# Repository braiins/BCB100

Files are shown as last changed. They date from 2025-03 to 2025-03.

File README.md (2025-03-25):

**Product Description**

This is final production release of Braiins BCB100.

**Hardware features**

- Compatible with all s19 models with the exception of Hydro models.
- Easy installation - compatible with the standard enclosures.
- SD Card slot
- LEDs
- Ethernet port
- Immersion ready
- It is based on MPU STM32MP157C/F with part number STM32MP157CAB3. Two core 650MHz A7 with ARM ISA and Cortex M3
  coprocessor. Package is LFBGA354 16x16
- 128 MB RAM and 4GB of eMMC memory
- Ethernet connection is based on Ethernet PHY Microchip 8710 with 10/100 Mb connection
- Main power is 12V with discrete points of 3.3V/1.35 and 0.65V, for the MPU, RAM, eMMC, Ethernet PHY and rest of the
  active components

**Software features**

- Full support of Braiins OS+

**Dimensions**

- Height: 110mm
- Width:100mm
- Weight:  ~130g

By default the board is powered by 12V from the auxiliary part of the PSU with a standard connector.
On the control board there are multiple discrete voltage points for the MPU, RAM, eMMC and Ethernet PHY. Discrete
voltage map contains 12V as the main power supply, 3.3V(eMMC, Ethernet PHY, OP-AMP) for multiple active components,
1.35V for the MPU/RAM and 0.65V for RAM as a reference voltage. MPU on the control board is from ST company with 2 ISA
ARM A7 cores 650 MHZ with M3 co-processor for smooth run.
Package is LFBGA354 16X16 part number STM32MP157CAB3. Operating memory is provided by Micron with a density 128MB. The
control board has two parts which can provide storage and boot capability.
First one is eMMC memory from company Alliance Memory with density 4GB. By default eMMC is chosen as the default boot
option. Second possibility for storage and OS boot is an SD card.
When the SD card is inserted during successful OS boot from eMMC, the MPU must be reset by reset button and after reset
the MPU will boot OS from the SD card.
Ethernet connection is secured by Ethernet PHY from company Microchip. It has a standard 10/100 Mb connection speed.
Board is built on the 6 layer PCB with 4 layers for data connections and 2 layers for power and ground to ensure proper
board running without cross talking or any other types of noise.
The control board mask was chosen black with a silicon layer for marks and signs. Parts on control boards are from both
sides of the board(top and bottom layer).
Current consumption on average is 250 mA.

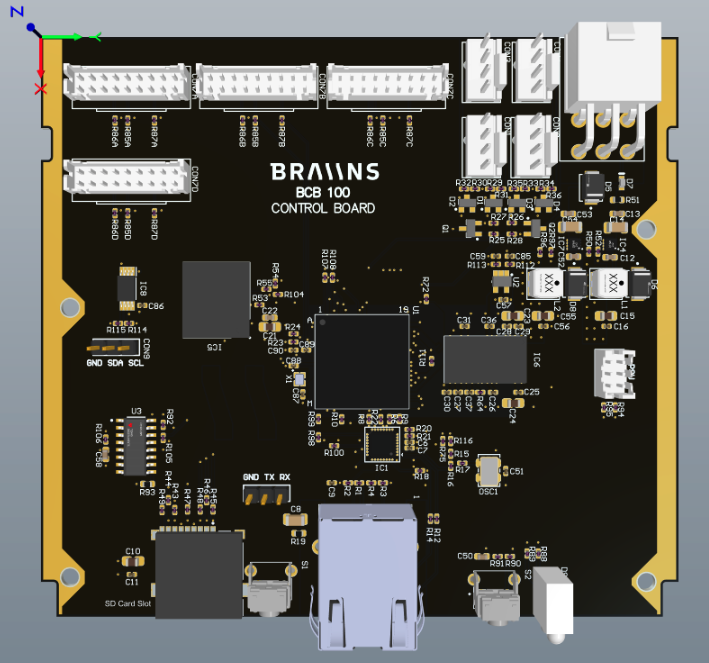
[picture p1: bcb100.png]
Braiins Control Board - BCB100


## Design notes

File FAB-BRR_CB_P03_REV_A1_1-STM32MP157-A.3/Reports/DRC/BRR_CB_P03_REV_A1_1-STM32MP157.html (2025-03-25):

Altium

# Design Rule Verification Report

Date: | | 25. 3. 2025
Time: | | 9:34:08
Elapsed Time: | | 00:00:02
Filename: | | C:\Users\Richard Tomasovic\AppData\Local\Temp\Releases\Snapshot\1\BRR_CB_P03_REV_A1_1-STM32MP157.PcbDoc

Warnings: | | 0
Rule Violations: | | 0
Waived Violations: | | 16

## Summary

Warnings | Count
Total | 0

Rule Violations | Count
Clearance Constraint (Gap=0.151mm) (All),(All) | 0
Clearance Constraint (Gap=0.102mm) (WithinRoom('MPU_BGA')),(All) | 0
Clearance Constraint (Gap=0.102mm) (WithinRoom('RAM')),(All) | 0
Clearance Constraint (Gap=0.102mm) (WithinRoom('EMMC')),(All) | 0
Clearance Constraint (Gap=0.102mm) (InNetClass('SINGLE_55R_DDR')),(All) | 0
Clearance Constraint (Gap=0.506mm) (InNet('NetC1_1') and InPolygon),(All) | 0
Clearance Constraint (Gap=0.506mm) (OnLayer('Int1 (GND)')),(All) | 0
Clearance Constraint (Gap=0.5mm) (HasFootprint('FID_1MM')),(All) | 0
Clearance Constraint (Gap=0.102mm) ((InDifferentialPairClass('All Differential Pairs'))),(All) | 0
Clearance Constraint (Gap=0.254mm) (InPolygon),(All) | 0
Short-Circuit Constraint (Allowed=No) (All),(All) | 0
Un-Routed Net Constraint ( (All) ) | 0
Modified Polygon (Allow modified: No), (Allow shelved: No) | 0
Width Constraint (Min=0.044mm) (Max=0.145mm) (Preferred=0.089mm) (InNetClass('50R_SDMMC1')) | 0
Width Constraint (Min=0.031mm) (Max=0.12mm) (Preferred=0.077mm) (InNetClass('SINGLE_55R_DDR')) | 0
Width Constraint (Min=0.102mm) (Max=0.305mm) (Preferred=0.203mm) (All) | 0
Width Constraint (Min=0.17mm) (Max=0.5mm) (Preferred=0.254mm) (InNet('DDR_VREF')) | 0
Width Constraint (Min=0.102mm) (Max=0.305mm) (Preferred=0.16mm) (WithinRoom('RAM')) | 0
Width Constraint (Min=0.044mm) (Max=0.145mm) (Preferred=0.089mm) (InNetClass('50R_SDMMC2')) | 0
Power Plane Connect Rule(Relief Connect )(Expansion=0.508mm) (Conductor Width=0.254mm) (Air Gap=0.254mm) (Entries=4) (All) | 0
Hole Size Constraint (Min=0.2mm) (Max=6mm) (All) | 0
Hole To Hole Clearance (Gap=0.254mm) (All),(All) | 0
Minimum Solder Mask Sliver (Gap=0mm) (All),(All) | 0
Silk To Solder Mask (Clearance=0mm) (IsPad),(All) | 0
Silk to Silk (Clearance=0mm) (All),(All) | 0
Net Antennae (Tolerance=0mm) (All) | 0
Board Clearance Constraint (Gap=0mm) (All) | 0
Length Constraint (Min=0mm) (Max=100mm) (InNetClass('50R_SDMMC1')) | 0
Matched Lengths(Tolerance=2mm) (InNetClass('50R_SDMMC1')) | 0
Matched Lengths(Delay Tolerance=5ps) (InDifferentialPairClass('DIFF_100R_DDR')) | 0
Matched Lengths(Delay Tolerance=10ps) (InDifferentialPairClass('ETH_100R')) | 0
Matched Lengths(Tolerance=3mm) (InxSignalClass('DDR3')) | 0
Matched Lengths(Tolerance=1mm) (InxSignalClass('SDMMC2')) | 0
Matched Lengths(Delay Tolerance=10ps) (InDifferentialPairClass('DIFF_100R_DDR')) | 0
Matched Lengths(Delay Tolerance=5ps) (InDifferentialPairClass('ETH_100R')) | 0
Maximum Via Count Constraint (Limit=2) (InNetClass('SINGLE_55R_DDR')) | 0
Room U_HBInterface_1 (Bounding Region = (8.255mm, 28.068mm, 24.255mm, 50.068mm) (InComponentClass('U_HBInterface_1')) | 0
Room EMMC (Bounding Region = (43.855mm, 20.668mm, 62.655mm, 42.664mm) (InComponentClass('Room Definition1')) | 0
Room U_HBInterface_0 (Bounding Region = (8.255mm, 6.068mm, 24.255mm, 28.068mm) (InComponentClass('U_HBInterface_0')) | 0
Room U_HBInterface_2 (Bounding Region = (8.255mm, 50.068mm, 24.255mm, 72.068mm) (InComponentClass('U_HBInterface_2')) | 0
Room RAM (Bounding Region = (57.355mm, 68.668mm, 71.255mm, 86.168mm) (False) | 0
Room MPU_BGA (Bounding Region = (54.455mm, 46.968mm, 73.855mm, 65.168mm) (False) | 0
Room U_HBInterface_3 (Bounding Region = (24.255mm, 6.068mm, 40.255mm, 28.068mm) (InComponentClass('U_HBInterface_3')) | 0
Height Constraint (Min=0mm) (Max=25.4mm) (Prefered=12.7mm) (All) | 0
Total | 0

Waived Violations | Count
Board Clearance Constraint (Gap=0mm) (All) | 15
Maximum Via Count Constraint (Limit=2) (InNetClass('SINGLE_55R_DDR')) | 1
Total | 16

## Rule Violations

## Waived Violations

Board Clearance Constraint (Gap=0mm) (All)

Board Outline Clearance(Outline Edge): (Collision < 0.381mm) Between Board Edge And Track (0.1mm,104.1mm)(21.4mm,104.1mm) on Top Overlay
Waived by Richard Tomašoviè at 14. 5. 2023 16:14:11

Board Outline Clearance(Outline Edge): (Collision < 0.381mm) Between Board Edge And Track (0.1mm,89.5mm)(0.1mm,104.1mm) on Top Overlay
Waived by Richard Tomašoviè at 14. 5. 2023 16:14:14

Board Outline Clearance(Outline Edge): (Collision < 0.381mm) Between Board Edge And Track (0.1mm,89.5mm)(21.4mm,89.5mm) on Top Overlay
Waived by Richard Tomašoviè at 14. 5. 2023 16:14:18

Board Outline Clearance(Outline Edge): (Collision < 0.381mm) Between Board Edge And Track (101.95mm,47.925mm)(101.95mm,64.025mm) on Top Overlay
Waived by Richard Tomašoviè at 14. 5. 2023 16:14:07

Board Outline Clearance(Outline Edge): (Collision < 0.381mm) Between Board Edge And Track (89.78mm,47.925mm)(101.95mm,47.925mm) on Top Overlay
Waived by Richard Tomašoviè at 14. 5. 2023 16:14:03

Board Outline Clearance(Outline Edge): (Collision < 0.381mm) Between Board Edge And Track (89.78mm,64.025mm)(101.95mm,64.025mm) on Top Overlay
Waived by Richard Tomašoviè at 14. 5. 2023 16:14:05

Board Outline Clearance(Outline Edge): (0.073mm < 0.381mm) Between Board Edge And Track (97.05mm,20.1mm)(99.8mm,20.1mm) on Top Overlay
Waived by Richard Tomašoviè at 14. 5. 2023 16:13:58

Board Outline Clearance(Outline Edge): (0.073mm < 0.381mm) Between Board Edge And Track (97.05mm,20.1mm)(99.8mm,20.1mm) on Top Overlay
Waived by Richard Tomašoviè at 14. 5. 2023 16:14:01

Board Outline Clearance(Outline Edge): (0.073mm < 0.381mm) Between Board Edge And Track (97.05mm,34.8mm)(99.8mm,34.8mm) on Top Overlay
Waived by Richard Tomašoviè at 14. 5. 2023 16:14:21

Board Outline Clearance(Outline Edge): (0.073mm < 0.381mm) Between Board Edge And Track (97.05mm,34.8mm)(99.8mm,34.8mm) on Top Overlay
Waived by Richard Tomašoviè at 14. 5. 2023 16:13:56

Board Outline Clearance(Outline Edge): (Collision < 0.381mm) Between Board Edge And Track (98.6mm,76.55mm)(99.95mm,76.55mm) on Top Overlay
Waived by Richard Tomašoviè at 18. 5. 2023 11:03:25

Board Outline Clearance(Outline Edge): (Collision < 0.381mm) Between Board Edge And Track (98.6mm,79.85mm)(99.95mm,79.85mm) on Top Overlay
Waived by Richard Tomašoviè at 18. 5. 2023 11:03:28

Board Outline Clearance(Outline Edge): (0.073mm < 0.381mm) Between Board Edge And Track (99.8mm,20.1mm)(99.8mm,34.8mm) on Top Overlay
Waived by Richard Tomašoviè at 14. 5. 2023 16:14:27

Board Outline Clearance(Outline Edge): (0.073mm < 0.381mm) Between Board Edge And Track (99.8mm,20.1mm)(99.8mm,34.8mm) on Top Overlay
Waived by Richard Tomašoviè at 14. 5. 2023 16:14:23

Board Outline Clearance(Outline Edge): (Collision < 0.381mm) Between Board Edge And Track (99.95mm,76.55mm)(99.95mm,79.85mm) on Top Overlay
Waived by Richard Tomašoviè at 18. 5. 2023 11:03:32

Back to top

Maximum Via Count Constraint (Limit=2) (InNetClass('SINGLE_55R_DDR'))

Maximum Via Count Constraint: Net DDR3_CSN (Via Count=3)
Waived by Richard Tomašoviè at 26. 5. 2023 16:26:37

Back to top

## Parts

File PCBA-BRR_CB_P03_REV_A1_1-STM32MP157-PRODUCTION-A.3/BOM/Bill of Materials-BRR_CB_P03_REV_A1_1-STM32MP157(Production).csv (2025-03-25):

Comment | Description | Designator | Footprint | LibRef | Quantity
HR915340A | 10BASE-T/100BASE-T Connector with internal magnetics | 1 | HR915340A | 30130 | 1
100n | CAP CER 100n 10% 6.3V 0402 | C1, C2, C4, C11, C16, C25, C26, C27, C28, C29, C30, C31, C32, C33, C34, C35, C36, C37, C38, C39, C40, C41, C42, C43, C44, C45, C46, C47, C48, C49, C51, C56, C59, C85, C91, C94 | CAP0402 | 30154 | 36
10u | CAP CER 10u 10% 6.3V X7R 0805 | C3, C5, C10, C15, C19, C23, C24, C55 | CAP0805 | 30174 | 8
470p | CAP CER 470p 10% 6.3V X7R 0402 | C6 | CAP0402 | 30163 | 1
1u | CAP CER 1u 10% 6.3V X7R 0402 | C7, C60, C61, C62, C63, C64, C65, C66, C67, C68, C69, C70, C71, C72, C73, C74, C75, C76, C77, C78, C81, C82, C83, C84, C95A, C95B, C95C, C95D, C96A, C96B, C96C, C96D | CAP0402 | 30155 | 32
1n | CAP CER 1n 5% 2000V 1206 | C8 | CAP1206 | 30107 | 1
22n | CAP CER 22n 10% 6.3V X7R 0402 | C9 | CAP0402 | 30161 | 1
100n | CAP CER 100n 10% 25V X7R 0603, CAP CER 100n 10% 6.3V X7R 0603 | C12, C13, C18, C20, C22, C52, C53 | CAP0603 | 30172, 30140 | 7
10u | CAP CER 10u 10% 25V X7R 1206 | C14, C54 | CAP1206 | 30171 | 2
4u7 | CAP CER 4u7 10% 6.3V X7R 0805 | C17, C21 | CAP0805 | 30175 | 2
470n | CAP CER 470n 10% 50V 0603 | C50 | CAP0603 | 30133 | 1
10u | CAP CER 10u 10% 6.3V 0603 X5R | C57, C58, C92, C93 | CAP0603 | 30139 | 4
1n | CAP CER 1n 10% 50V X7R 0402, CAP CER 1n 10% 10V X7R 0402 | C79, C80, C89 | CAP0402 | 30076, 30168 | 3
470uF | CAP ELECT 470uF ±20% 6.3V Radial, Can - SMD | C86, C97, C98 | CAP_EEEFTJ471XAP | 30239 | 3
10p | CAP CER 10p 10% 10V X7R 0402 | C87, C88 | CAP0402 | 30167 | 2
10n | CAP CER 10n 10% 10V X7R 0402 | C90 | CAP0402 | 30169 | 1
MOLEX 47053-1000 | MOLEX KK254 4pin with LOCK, MALE | CON1, CON2, CON3, CON4 | MOLEX_47053-1000_BIGPADS | 30102 | 4
MR01A-01211 | Micro SD card connector with card detect | CON5 | MR01A01211 | 30104 | 1
C4201WR-2x3P | CB Power Supply Connector | CON6 | MOLEX_39301061 | 30196 | 1
A2008WV-2x9P | Connector THT, vertical, 2mm pitch | CON7A, CON7B, CON7C, CON7D | A2008WV-2X9P | 30124 | 4
PHD 2*3P | Miner Power Supply Com Connector 2x3pin | CON8 | C4201WR-2x3P | 30148 | 1
Connector 3pin | Pin Header 1x3, 2.54mm | CON10 | PIN_HEADER_254_3 | 30103 | 1
STPS3L60U | DIODE SCHOTTKY 60V 3A SMB | D5, D6, D8 | FP-SMB-MFG | CMP-12187-000023-1 | 3
FYLS-0603UGC | LED Uni-Color Green, 52 mW, 20 mA, -40 to 85 degC, 2-Pin SMD, RoHS, Tape and Reel | D7 | AVAG-HSMX-C190_V | CMP-007-00013-2 | 1
BIVAR_HC301 | DUAL LED TERMINAL | D9 | BIVAR_HC301 | 30151 | 1
BLM15AG601SN1D | Chip Ferrite Bead, 0402, 600? @ 100MHz, 0.52?, 25%, 300mA | FB1 | FP-BLM15-0_05-MFG | CMP-0686-00187-4 | 1
Fiducial | Fiducial 1mm | FID1, FID2, FID3, FID4, FID5, FID6 | FID_1MM | 30186 | 6
3 mm | Mechanical hole, non plated | H1, H2, H3, H4 | THT_HOLE_NONPLATE_3_0 | 30117 | 4
LAN8710A-EZC-ABC | 10BASE-T/100BASE-TX PHY | IC1 | QFN32 | 30126 | 1
AP2303MTR-G1 | IC REG CONV DDR 1OUT 8SOIC | IC2 | SOIC8 | 30185 | 1
TPS22919DCKR | Self-Protected Load Switch, 5.5 V, 1.5 A, 90-m? | IC3A, IC3B, IC3C, IC3D | SC-70 | 30187 | 4
AOZ1282DI | 1.2A buck regulator, 4.5V to 36V, 450kHz | IC4, IC7 | DFN8_2X2 | 30108 | 2
ASFC4G31M-51BIN | IC FLASH 4GB MMC 153FBGA | IC5 | BGA153C50P14X14_1150X1300X100 | 30134 | 1
MT41K128M16JT-125:K TR | IC DRAM 2GBIT PARALLEL 96FBGA | IC6 | BGA96C80P9X16_800X1400X120 _0.35 | 30135 | 1
22uH | INDUCTOR 22uH ±20% 1.8A | L1, L2 | VLS5045EX | 30147 | 2
MH3261-601Y | FERRITE BEAD 600 OHM 1206 1LN | L3 | RES1206 | 30184 | 1
ECS-5032MV-500-BN-TR | XTAL OSC 50MHZ HCMOS SMD | OSC1 | 5032_CLOCK_GEN | 30144 | 1
2N7002 | N-Channel OptiMOS Small-Signal-Transistor, 60 V VDS, 0.3 A ID, -55 to 150 degC, PG-SOT23, Reel, Green | Q1, Q2, Q3 | INF-PG-SOT23_M | CMP-1149-00026-1 | 3
49R9 | RES 49R9 Ohm 1% 0402 | R1, R2, R3, R4 | RES0402 | 30160 | 4
10k | RES 10k Ohm 1% 0402, RES 10k Ohm 0.1% 0402 | R5, R6, R7, R9, R20, R21, R22, R53, R54, R55, R56, R68, R72, R97, R103, R112, R113 | RES0402 | 30071, 30177 | 17
1k5 | RES 1k5 Ohm 1% 0402 | R8, R98 | RES0402 | 30158 | 2
10R | RES 10R Ohm 1% 0402 | R10, R11, R13 | RES0402 | 30162 | 3
330R | RES 330R Ohm 1% 0402 | R12, R14 | RES0402 | 30083 | 2
33R | RES 33R Ohm 1% 0402 | R15, R16 | RES0402 | 30088 | 2
0R | RES 0R Ohm 1% 0402 | R17, R75, R106, R117, R118, R119 | RES0402 | 30178 | 6
12k1 | RES 12k1 Ohm 1% 0402 | R18 | RES0402 | 30159 | 1
1M | RES 1M Ohm 0,01 0603 (1608 Metric) | R19 | RES0603 | 30054 | 1
4k7 | RES 4k7 Ohm 1% 0402 | R23, R24, R27, R28, R29, R30, R33, R34, R85A, R85B, R85C, R85D, R86A, R86B, R86C, R86D, R87A, R87B, R87C, R87D, R92, R93, R94, R95, R107, R108, R109, R110, R120A, R120B, R120C, R120D | RES0402 | 30073 | 32
22R | RES 22R Ohm 1% 0402 | R25, R26, R31, R32, R35, R36, R43, R44, R45, R46, R47, R48, R99, R100, R101, R102, R104, R105 | RES0402 | 30156 | 18
47k | RES 47k Ohm 1% 0402 | R37, R38, R39, R40, R41, R42 | RES0402 | 30157 | 6
56R | RES 56R Ohm 1% 0402 | R49, R57, R58, R59, R60, R61, R62, R65, R66, R67, R69, R70, R71, R73, R74, R76, R77, R78, R79, R80, R81, R82, R83, R84 | RES0402 | 30143 | 24
49k9 | RES 49k9 Ohm 1% 0402 | R50 | RES0402 | 30164 | 1
10k | RES 10k Ohm 1% 0603 | R51 | RES0603 | 30092 | 1
15k8 | RES 15k8 Ohm 1% 0402 | R52 | RES0402 | 30165 | 1
100R | RES 100R Ohm 1% 0402 | R63 | RES0402 | 30142 | 1
240R | RES 240R Ohm 1% 0402 | R64, R111 | RES0402 | 30141 | 2
470R | RES 470R Ohm 1% 0402 | R88, R89 | RES0402 | 30084 | 2
1k | RES 1k Ohm 1% 0402 | R90 | RES0402 | 30070 | 1
100k | RES 100k Ohm 1% 0402 | R91 | RES0402 | 30079 | 1
6k9 | RES 6k9 Ohm 1% 0402 | R96 | RES0402 | 30153 | 1
220R | RES 220R Ohm 1% 0402 | R114 | RES0402 | 30216 | 1
0R | RES 0R Ohm 1% 0603 | R121A, R121B, R121C, R121D | RES0603 | 30097 | 4
TL1105VF160Q | SWITCH TACTILE SPST-NO 0.05A 12V | S1 | SW_TL1105VF160Q | 30149 | 1
PTS645VL83-2 LFS | SWITCH TACTILE SPST-NO 0.05A 12V, LEVER 8.35mm | S2 | THT_TACTILE_75x45_8mm35 | 30182 | 1
1.5 mm | Testpoint SMT 1.5mm | TP1 | TESTPOINT_1_5MM | 30199 | 1
STM32MP157CAB3 | IC MPU STM32MP1 650MHZ 354LFBGA | U1 | LFBGA354_16X16 | 30145 | 1
FW2400080 | Crystal Ceramic 24MHz | X1 | XTAL_4PIN_20X16 | 30166 | 1

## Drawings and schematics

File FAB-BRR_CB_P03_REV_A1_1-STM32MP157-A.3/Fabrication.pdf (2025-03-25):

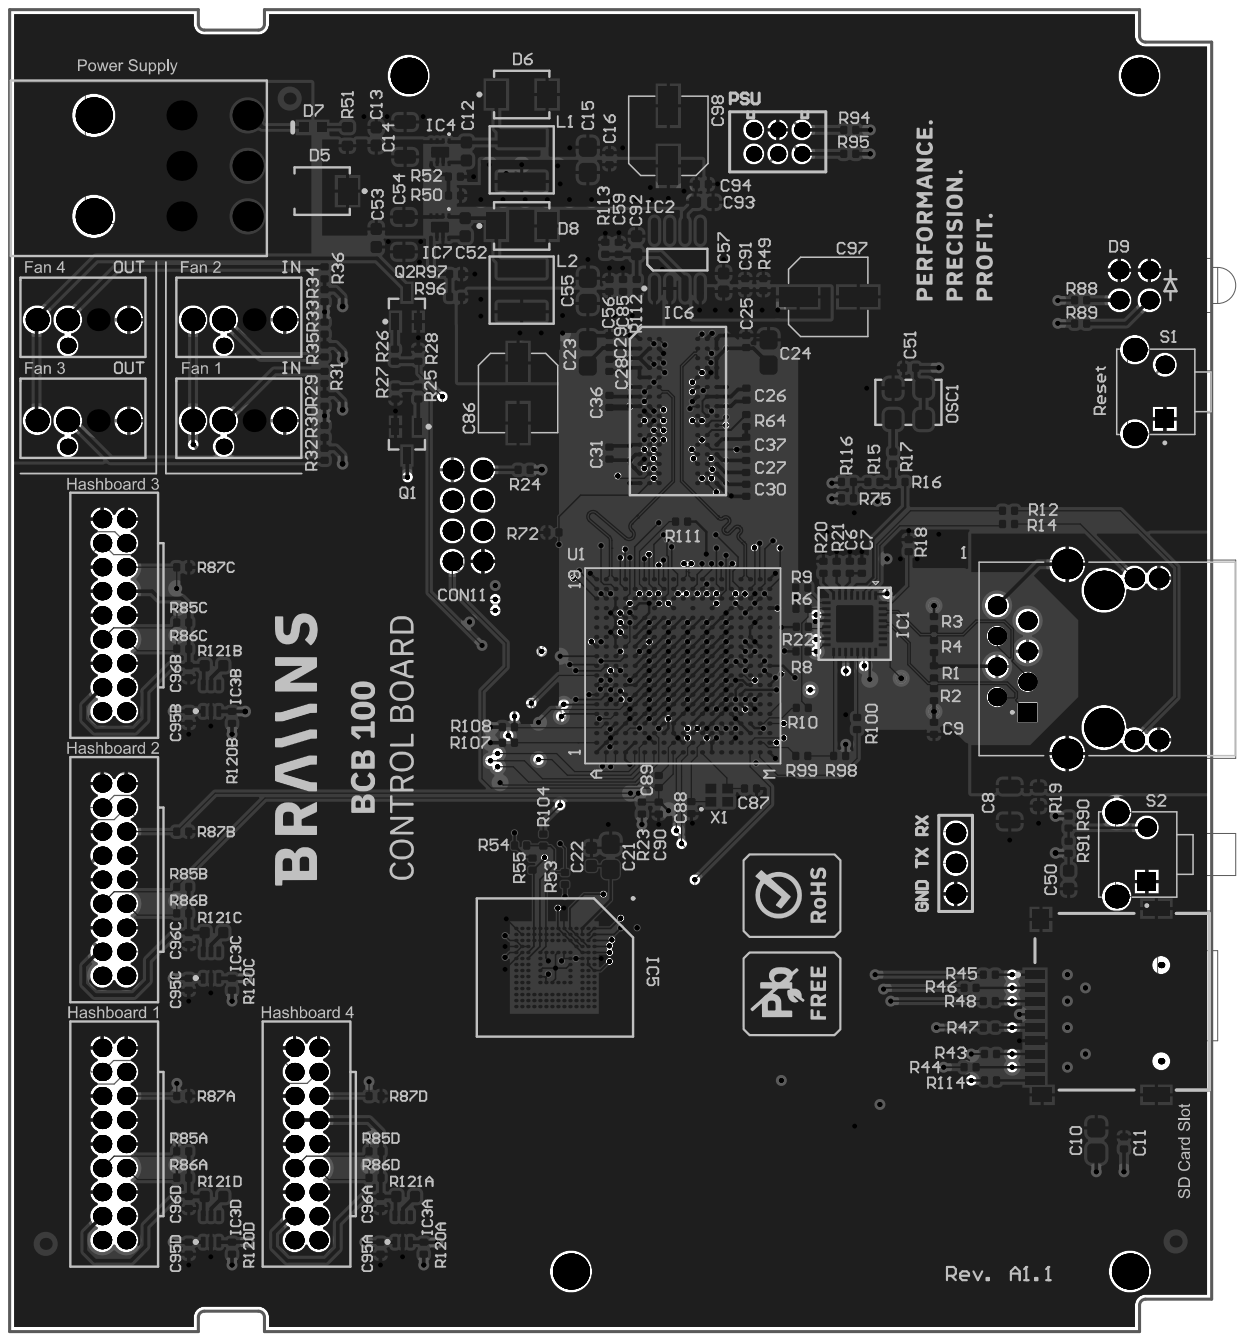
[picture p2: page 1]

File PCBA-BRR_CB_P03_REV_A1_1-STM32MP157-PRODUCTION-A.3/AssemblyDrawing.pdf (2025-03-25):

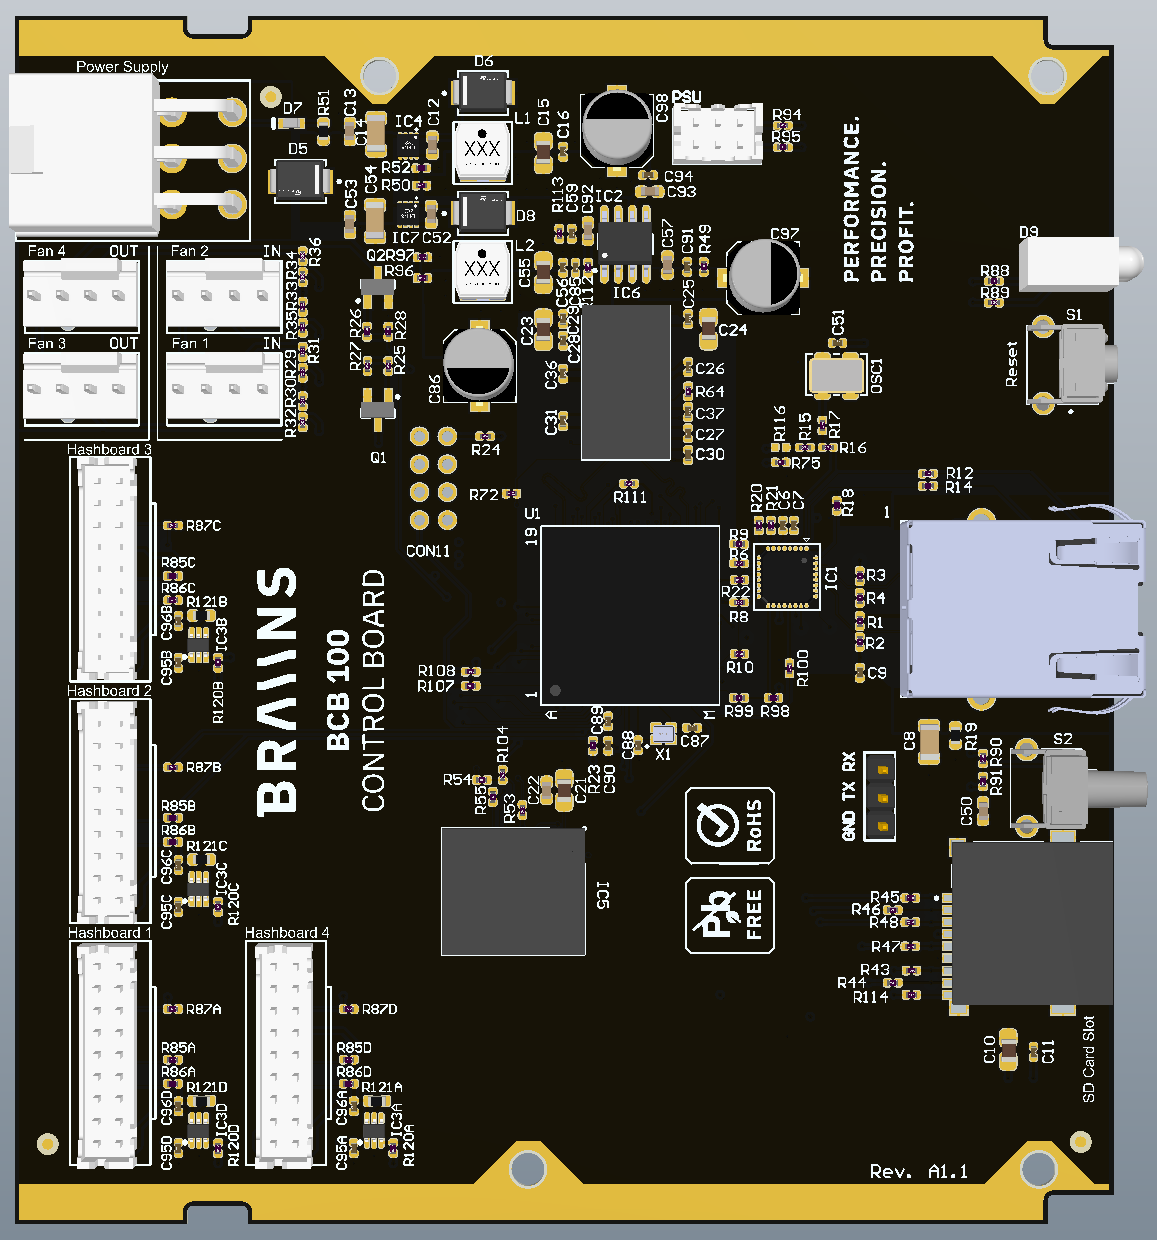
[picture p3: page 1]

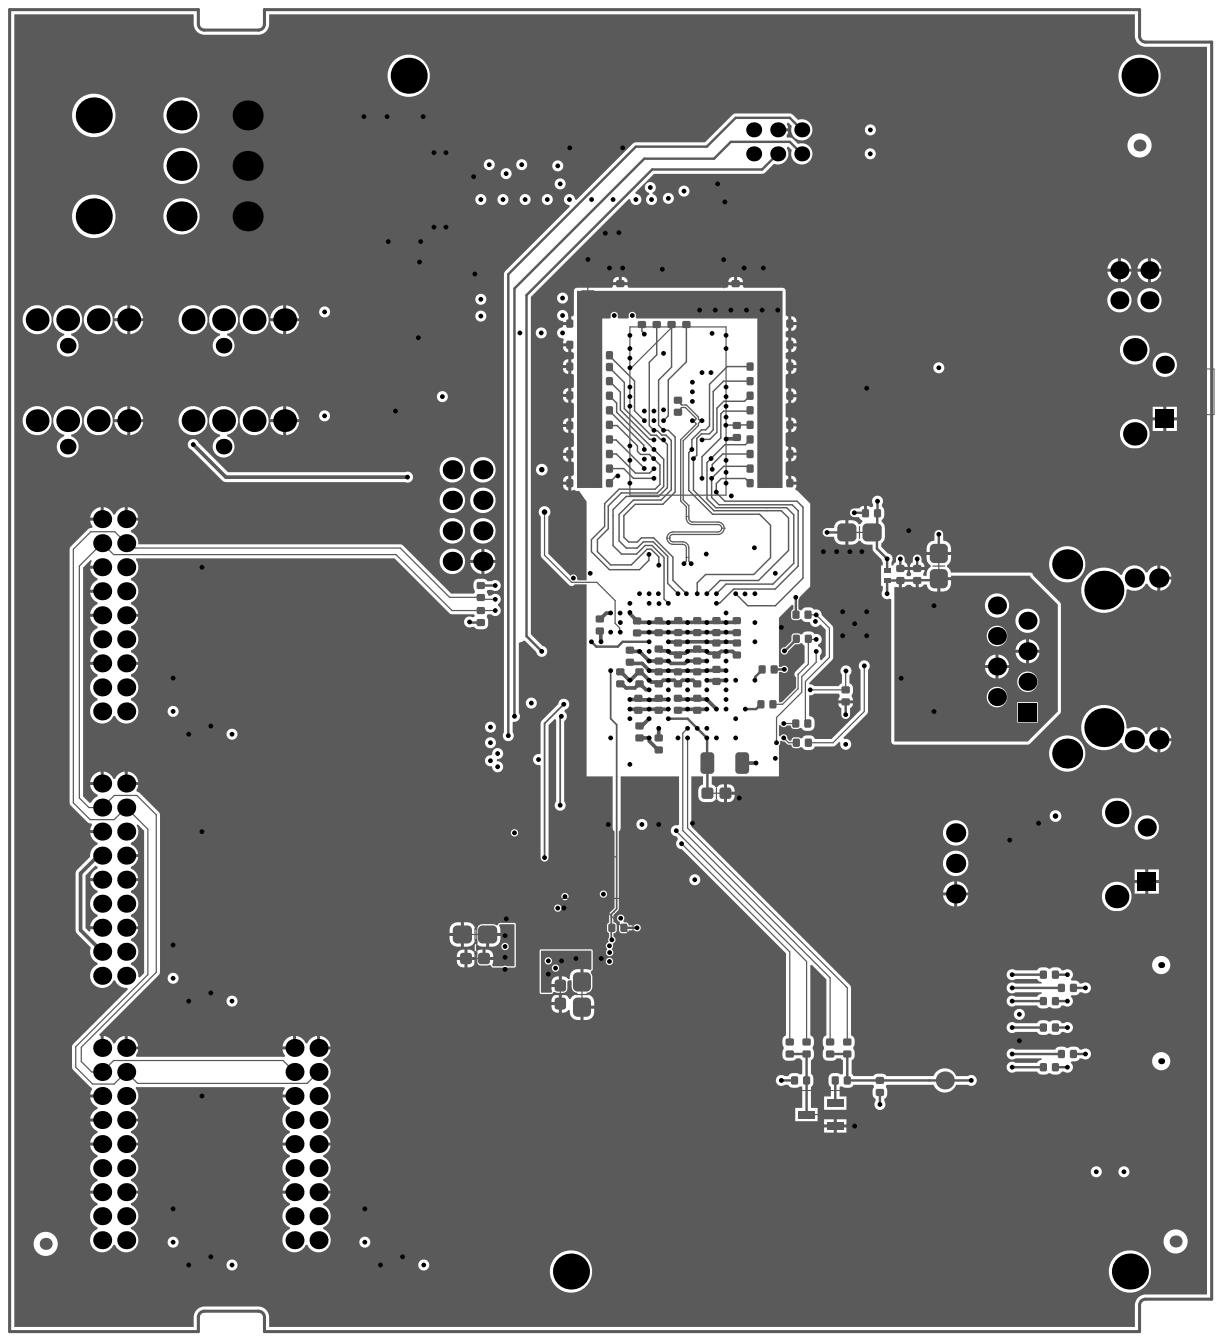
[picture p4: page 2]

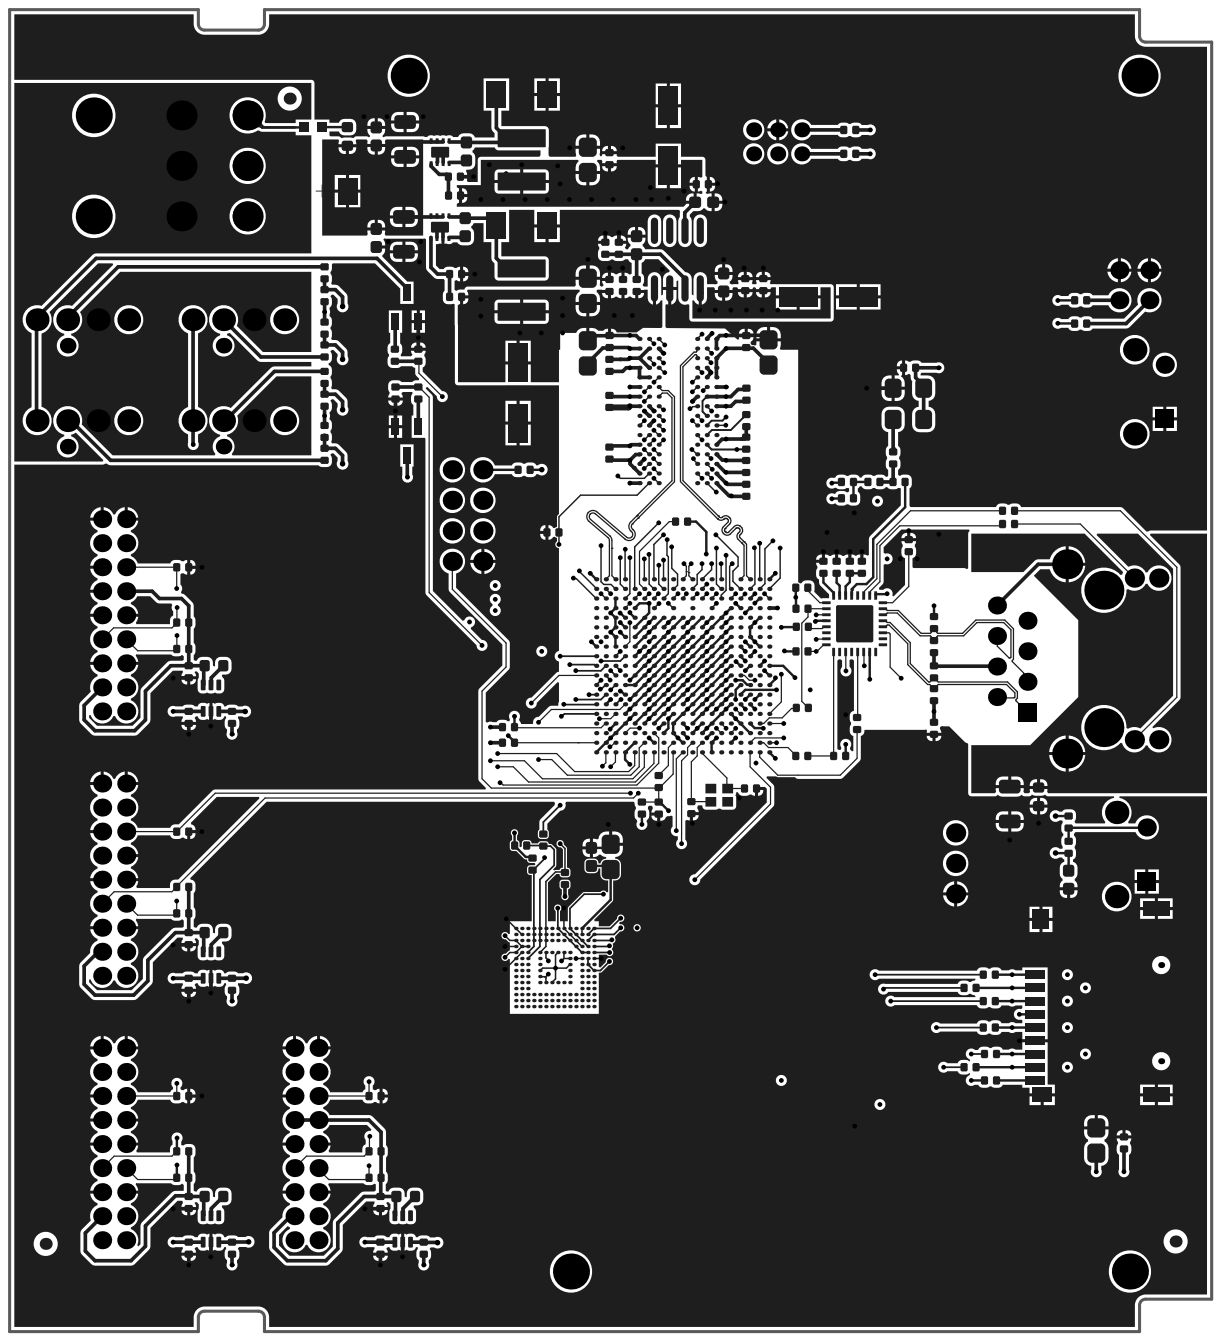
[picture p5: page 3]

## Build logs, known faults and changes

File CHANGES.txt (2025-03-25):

This file is intended to document modifications made to the design. 
As per section 3.3.b of the CERN-OHL-S v2 license, any modifications to this design must be documented with a brief entry including the date and nature of the modification. 
Entries should be added in chronological order, and no previous entries should be removed. 
***
- 26 April 2023: DCDC  to PMIC on RAM.
